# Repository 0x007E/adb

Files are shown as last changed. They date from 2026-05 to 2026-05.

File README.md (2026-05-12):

  

# `ADB` - Analog Development Board

The `ADB` is a board with an [LM358](#additional-information) or any other 2-channel operational amplifier that meets the pin requirements. The board itself can be driven from `0 to 30V` or `+/-15V`. The board offers the possibility to create standard `OPA` circuits with `THT` resistors/capacitors and inductors or any other external circuit.

| Experience | Level |
|:---|:-----:|
| Soldering | ?% |

# Downloads

| Type | File | Description |
|:---:|:---:|:---|
| Schematic | [pdf](https://github.com/0x007E/adb/releases/latest/download/schematic.pdf) / [cadlab](https://cadlab.io/project/29896/main/files) | Schematic files |
| Board | [pdf](https://github.com/0x007E/adb/releases/latest/download/pcb.pdf) / [cadlab](https://cadlab.io/project/29896/main/files) | Board file |
| Drill | [pdf](https://github.com/0x007E/adb/releases/latest/download/drill.pdf) | Drill file |
| PCB | [zip](https://github.com/0x007E/adb/releases/latest/download/kicad.zip) / [tar](https://github.com/0x007E/adb/releases/latest/download/kicad.tar.gz) |  	KiCAD/Gerber/BoM/Drill files |
| Mechanical | [zip](https://github.com/0x007E/adb/releases/latest/download/freecad.zip) / [tar](https://github.com/0x007E/adb/releases/latest/download/freecad.tar.gz) | FreeCAD/Housing and exported step/stl files |

# Hardware

The pcb is created with `KiCAD`. All files are built with `github actions` so that they are ready for a production environment.

## PCB

The circuit board is populated on both sides (Top, Bottom). The best way for soldering the `SMD` components is within a vapor phase soldering system and for the `THT` components with a standard soldering system.

### Top Layer

Top Layer

### Bottom Layer

Bottom Layer

# Additional Information

| Type | Link | Description |
|:---:|:---:|:---|
| LM358 | [pdf](https://www.onsemi.com/download/data-sheet/pdf/lm358-d.pdf) | Dual operational amplifier |

---

R. GAECHTER

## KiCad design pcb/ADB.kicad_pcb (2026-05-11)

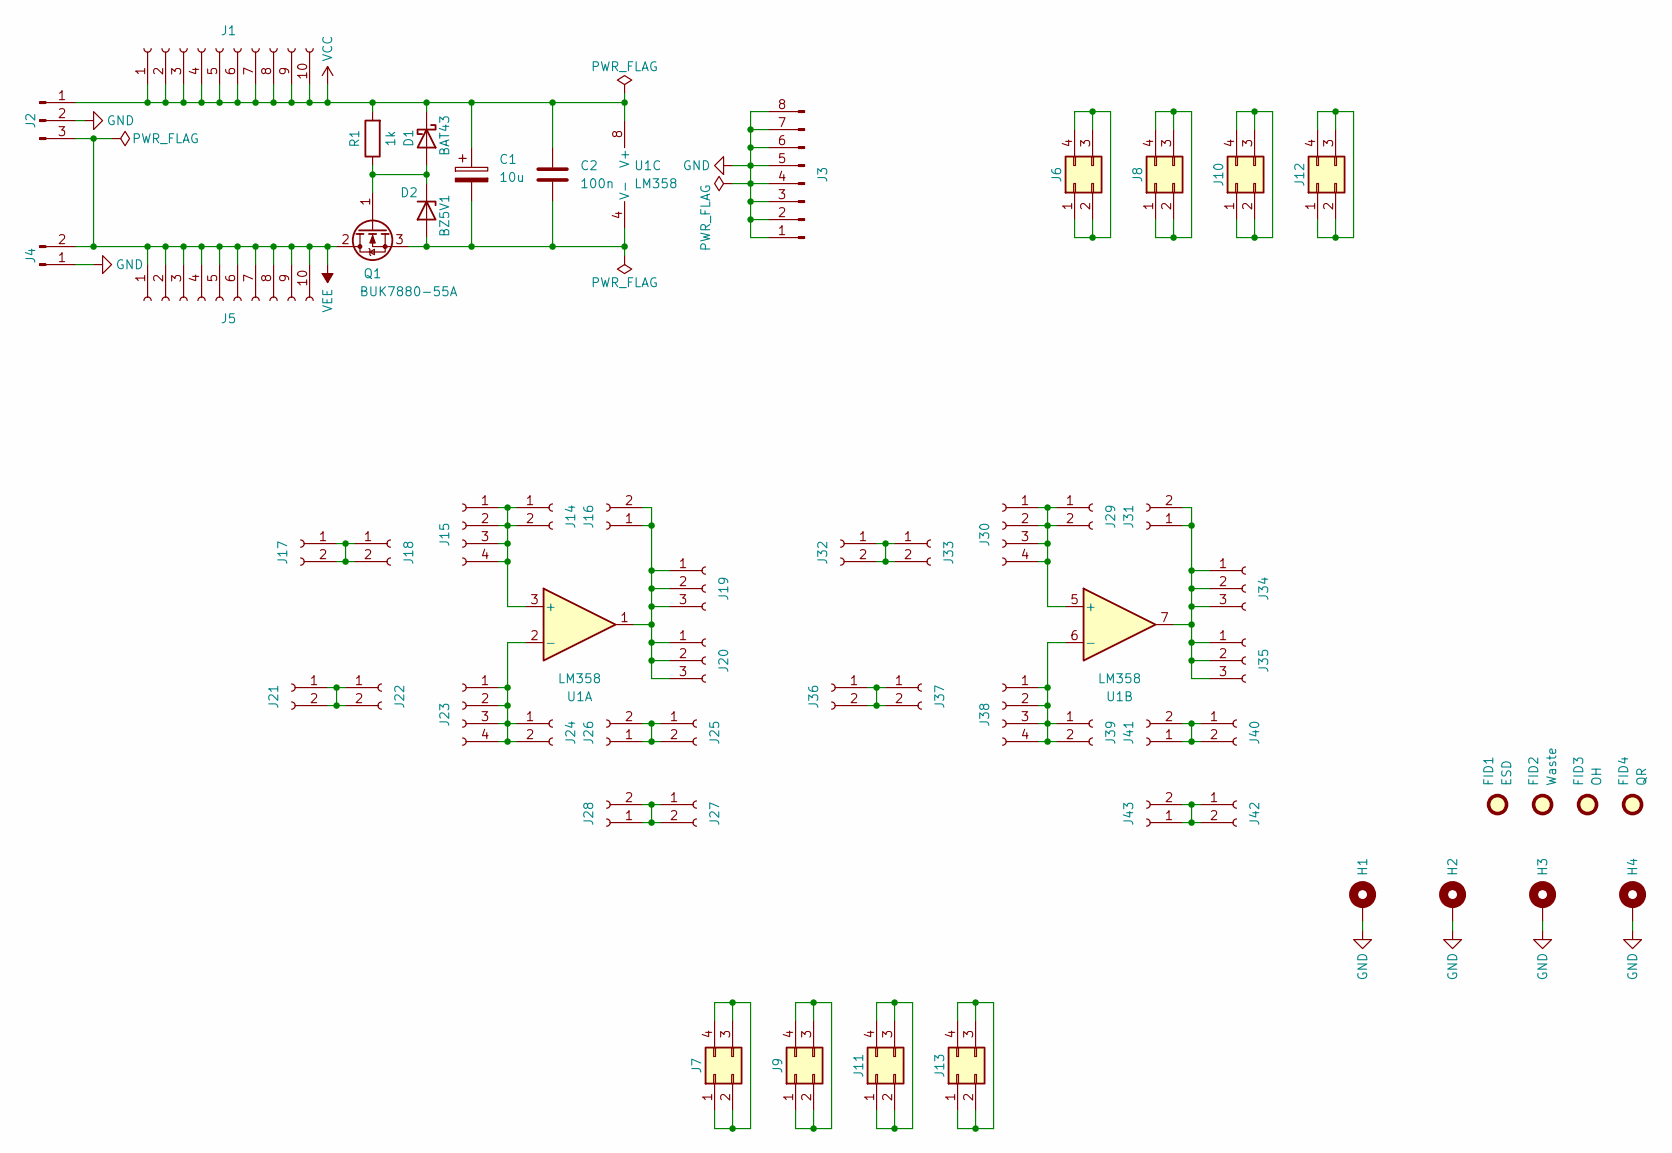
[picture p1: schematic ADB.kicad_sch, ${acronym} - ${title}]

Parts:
C1: 10u; CP_Radial_D6.3mm_P2.50mm
C2: 100n; C_1206_3216Metric
D1: BAT43; D_MiniMELF
D2: BZ5V1; D_MiniMELF
FID1: ESD; ESD-Logo_6.6x6mm_SilkScreen
FID2: Waste; WEEE-Logo_4.2x6mm_SilkScreen
FID3: OH; OSHW-Logo_5.7x6mm_SilkScreen
FID4: QR; QR_0x007e
H1, H2, H3, H4: MountingHole_Pad; MountingHole_3.2mm_M3_Pad
J1, J5: Conn_01x10_Socket; PinSocket_1x10_P2.54mm_Vertical
J2: Conn_01x03_Pin; PinHeader_1x03_P2.54mm_Vertical
J3: Conn_01x08_Pin; PinHeader_1x08_P2.54mm_Vertical
J4: Conn_01x02_Pin; PinHeader_1x02_P2.54mm_Vertical
J6, J7, J8, J9, J10, J11, J12, J13: Conn_02x02_Counter_Clockwise; PinSocket_2x02_P2.54mm_Vertical
J14, J16, J17, J18, J21, J22, J24, J25, J26, J27, J28, J29, J31, J32, J33, J36, J37, J39, J40, J41, J42, J43: Conn_01x02_Socket; PinSocket_1x02_P2.54mm_Vertical
J15, J23, J30, J38: Conn_01x04_Socket; PinSocket_1x04_P2.54mm_Vertical
J19, J20, J34, J35: Conn_01x03_Socket; PinSocket_1x03_P2.54mm_Vertical
Q1: BUK7880-55A; SOT-223-3_TabPin2
R1: 1k; R_1206_3216Metric
U1: LM358; SOIC-8_3.9x4.9mm_P1.27mm

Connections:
GND: H1.1, H2.1, H3.1, H4.1, J2.2, J3.1, J3.2, J3.3, J3.4, J3.5, J3.6, J3.7, J3.8, J4.1
unnamed: D1.2 (A), D2.1 (K), Q1.1 (G), R1.1
unnamed: C1.2, C2.2, D2.2 (A), Q1.3 (S), U1.4 (V-)
unnamed: J6.1, J6.2, J6.3, J6.4
unnamed: J7.1, J7.2, J7.3, J7.4
unnamed: J8.1, J8.2, J8.3, J8.4
unnamed: J9.1, J9.2, J9.3, J9.4
unnamed: J10.1, J10.2, J10.3, J10.4
unnamed: J11.1, J11.2, J11.3, J11.4
unnamed: J12.1, J12.2, J12.3, J12.4
unnamed: J13.1, J13.2, J13.3, J13.4
unnamed: J14.1, J14.2, J15.1, J15.2, J15.3, J15.4, U1.3 (+)
unnamed: J16.1, J16.2, J19.1, J19.2, J19.3, J20.1, J20.2, J20.3, U1.1
unnamed: J17.1, J17.2, J18.1, J18.2
unnamed: J21.1, J21.2, J22.1, J22.2
unnamed: J23.1, J23.2, J23.3, J23.4, J24.1, J24.2, U1.2 (-)
unnamed: J25.1, J25.2, J26.1, J26.2
unnamed: J27.1, J27.2, J28.1, J28.2
unnamed: J29.1, J29.2, J30.1, J30.2, J30.3, J30.4, U1.5 (+)
unnamed: J31.1, J31.2, J34.1, J34.2, J34.3, J35.1, J35.2, J35.3, U1.7
unnamed: J32.1, J32.2, J33.1, J33.2
unnamed: J36.1, J36.2, J37.1, J37.2
unnamed: J38.1, J38.2, J38.3, J38.4, J39.1, J39.2, U1.6 (-)
unnamed: J40.1, J40.2, J41.1, J41.2
unnamed: J42.1, J42.2, J43.1, J43.2
VCC: C1.1, C2.1, D1.1 (K), J1.1, J1.2, J1.3, J1.4, J1.5, J1.6, J1.7, J1.8, J1.9, J1.10, J2.1, R1.2, U1.8 (V+)
VEE: J2.3, J4.2, J5.1, J5.2, J5.3, J5.4, J5.5, J5.6, J5.7, J5.8, J5.9, J5.10, Q1.2 (D)

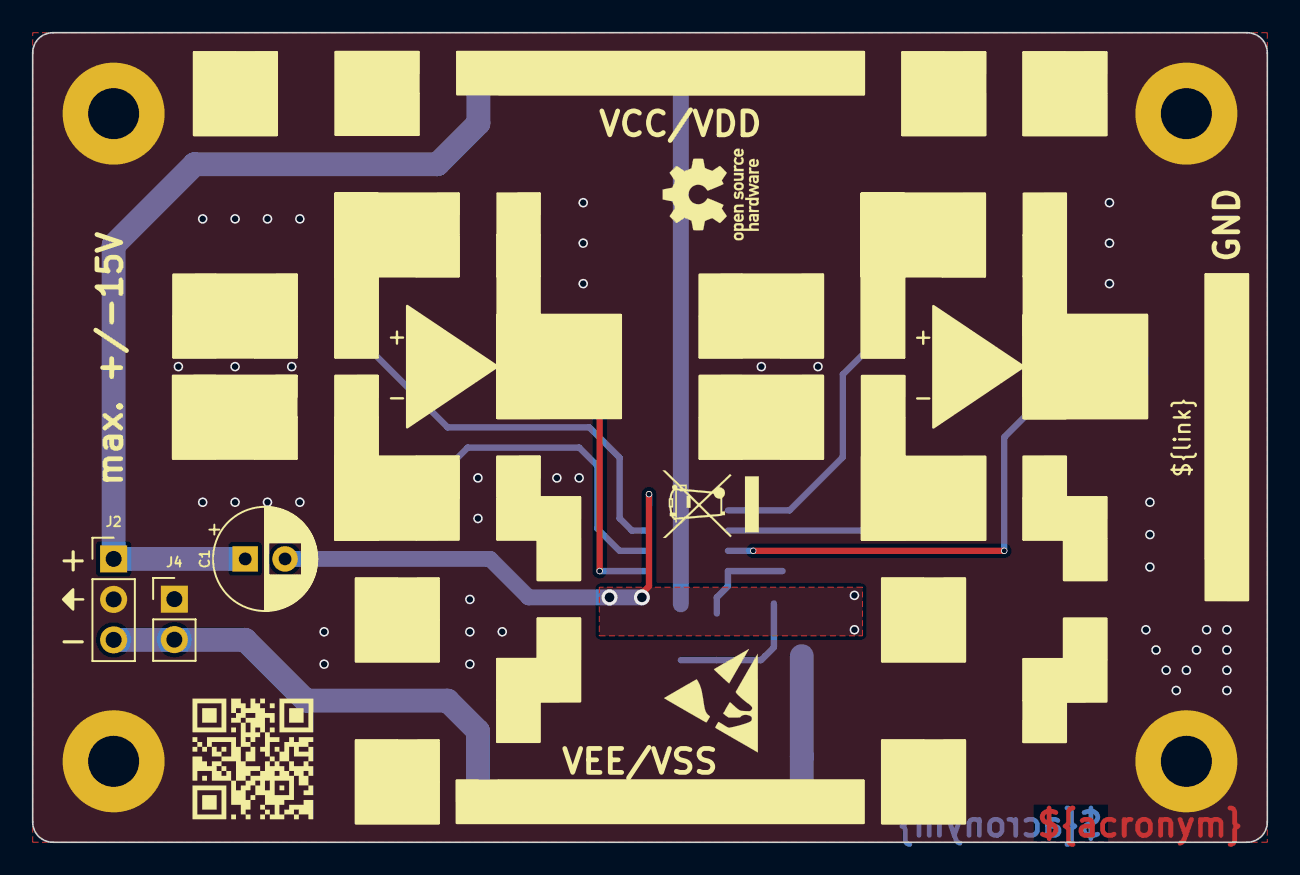
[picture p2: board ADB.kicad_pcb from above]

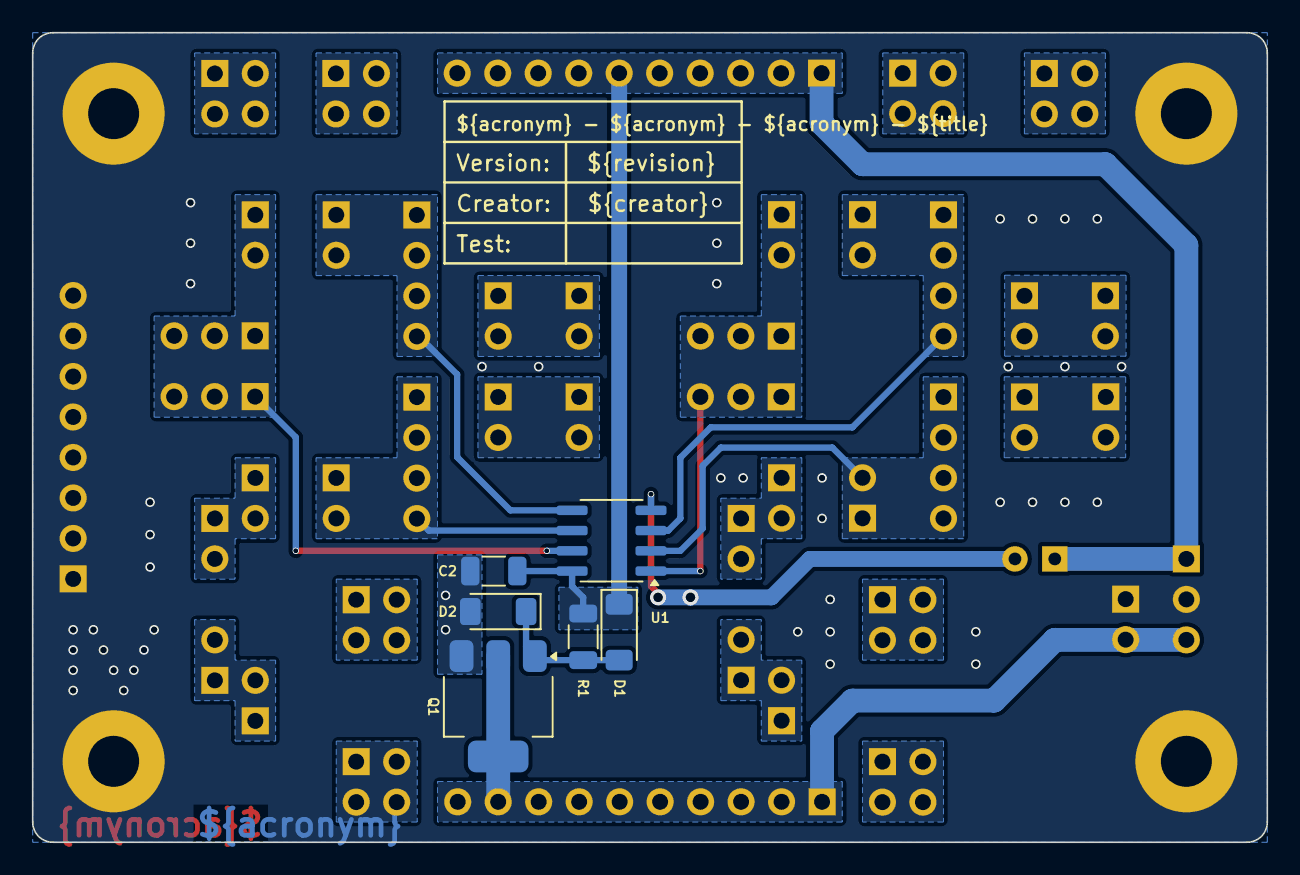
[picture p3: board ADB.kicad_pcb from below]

Board: 2 copper layers, 77.5 x 50.8 mm, 58 parts (6 on the bottom side), 27 nets.

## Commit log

2026-02-06 Add pcb layout
    [ADB.kicad_pcb, ADB.kicad_sch]
2026-02-06 Add more vias
    [ADB.kicad_pcb]
2026-02-06 Fix negative voltage descriptors
    [ADB.kicad_pcb, ADB.kicad_sch]
2026-02-07 Add gh-link
    [ADB.kicad_pcb]
2026-02-08 Reposition of U1 on silkscreen
    [ADB.kicad_pcb]
2026-03-22 Adapt edge cuts and dimensioning
    [ADB.kicad_pcb]
2026-05-08 Add reverse polarity protection
    [ADB.kicad_pcb, ADB.kicad_sch]
2026-05-09 Remove isolated copper filter
2026-05-09 Increase power trace width
    [ADB.kicad_pcb]
2026-05-11 Optimize fabrication layer
    [ADB.kicad_pcb]

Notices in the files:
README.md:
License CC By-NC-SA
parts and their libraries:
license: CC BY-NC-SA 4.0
